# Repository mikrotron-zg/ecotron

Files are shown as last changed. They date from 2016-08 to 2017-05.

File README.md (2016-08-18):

# ecotron
IoT trashcan by http://www.DIYKits.eu/

For hardware and related instructions, see
https://hackaday.io/project/13111-internet-of-trash

Software is split in three parts:

1) arduino
Firmware that performs measurements, and sends the data to the sever.
Build and install with Arduino IDE.

2) server
Collection of Java servlets to receive the data from devices, and display the data to clients.
Build with 'ant war', then deploy ecotron-server.war to your app server.

3) webapp
A web application that reads the data from the server, and displays it on the map.
Build with 'mvn clean install', then deploy target/ecotronmap-demo.war to your app server.

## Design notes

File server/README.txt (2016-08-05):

Server that receives the data from device(s) and stores them to the database.

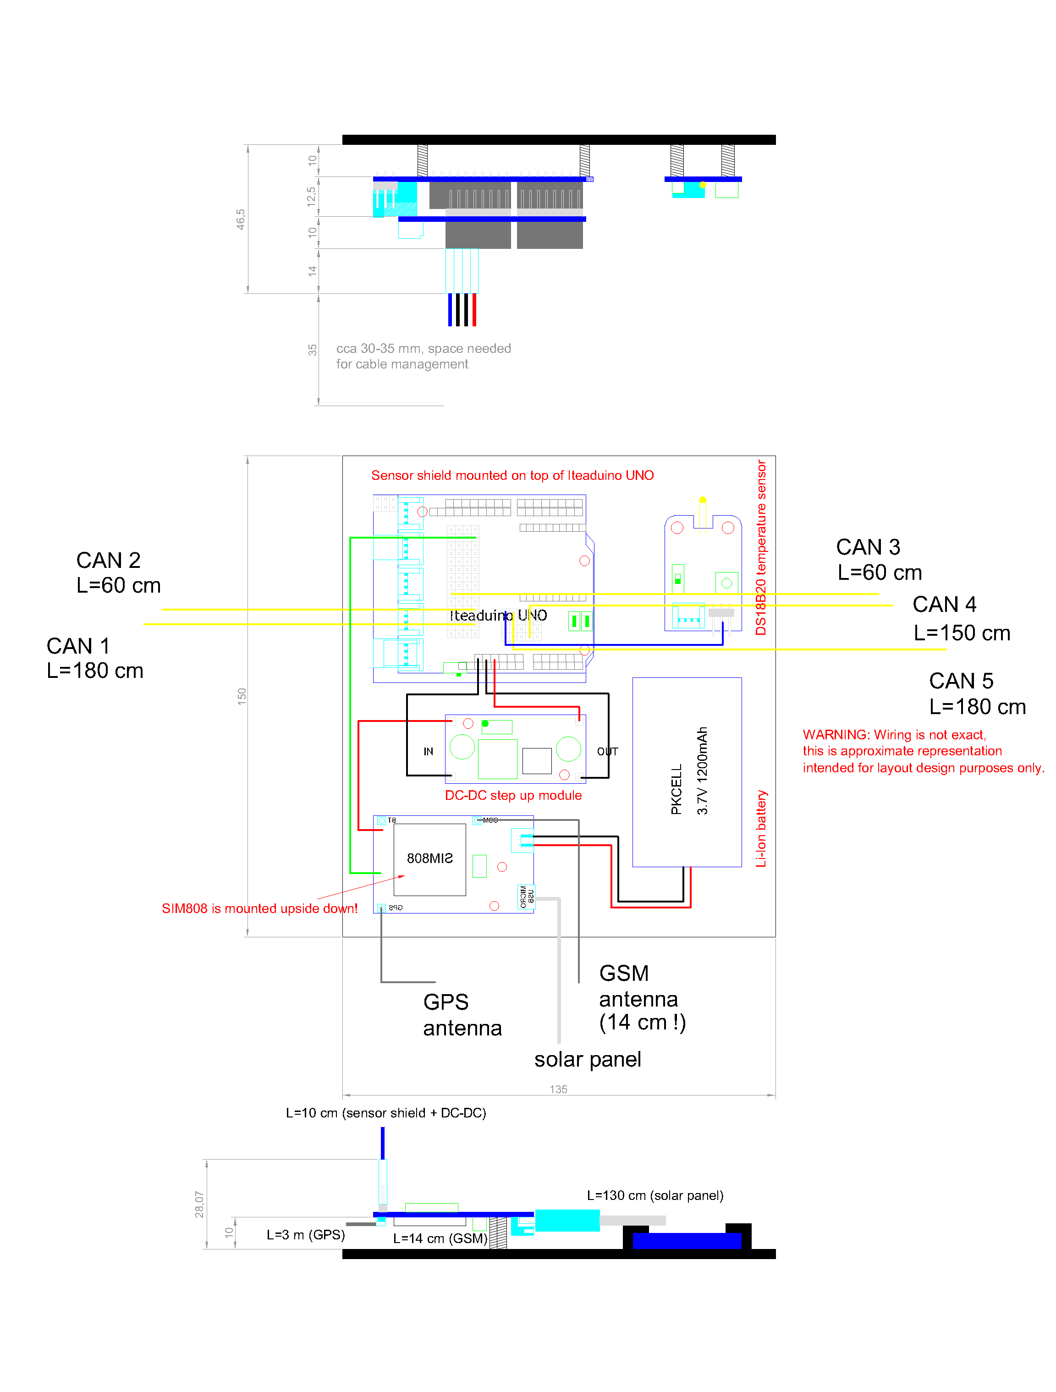
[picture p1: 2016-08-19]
hardware/EcotronControllerBox.png

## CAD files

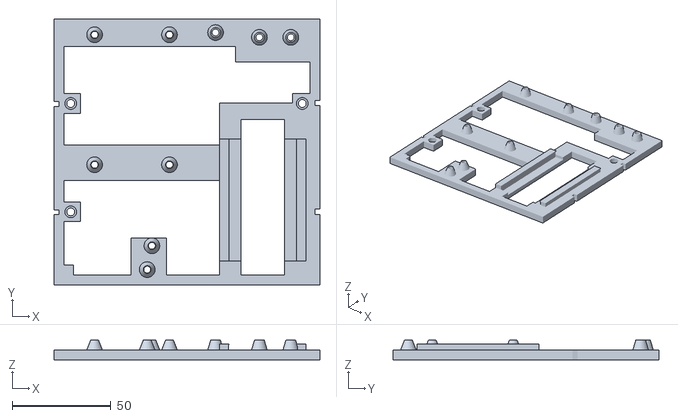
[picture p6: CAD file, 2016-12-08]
hardware/EcotronControllerBoxMount.stl
135.0 x 134.8 x 10.0

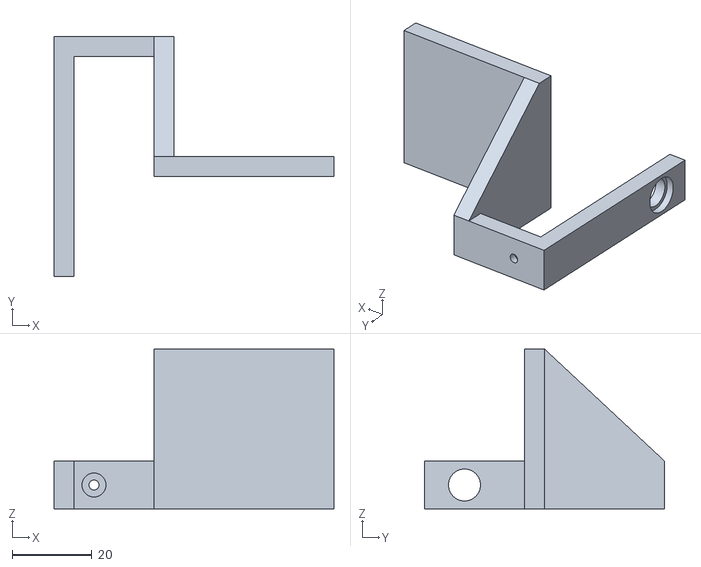
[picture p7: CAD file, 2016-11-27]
hardware/Antennas_mount.stl
70.0 x 60.0 x 40.0

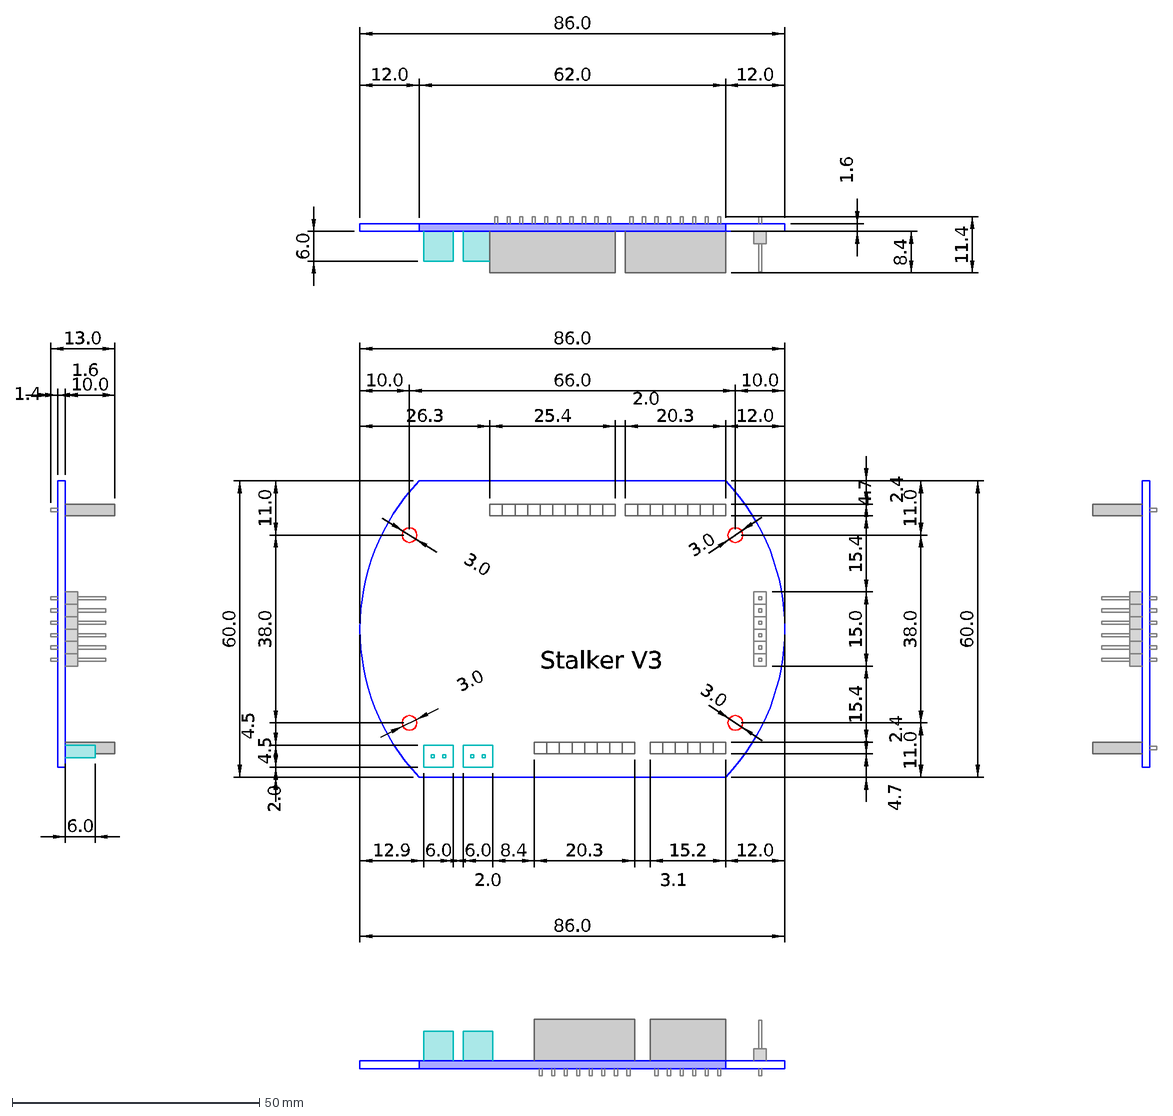
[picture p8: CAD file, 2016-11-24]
hardware/SeeeduinoStalkerV3.dxf
Stalker V3
86.0
12.0
62.0
10.0
66.0
26.3
25.4
2.0
20.3
60.0
11.0
38.0
4.7
2.4
15.4
15.0
3.0
11.4
8.4
1.6
6.0
12.9
3.1
15.2
4.5
13.0
1.4

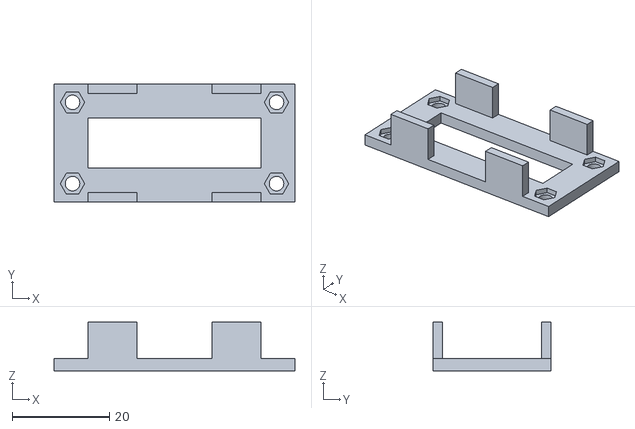
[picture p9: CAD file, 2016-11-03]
hardware/HC-SR04_mount.stl
49.5 x 24.3 x 10.0

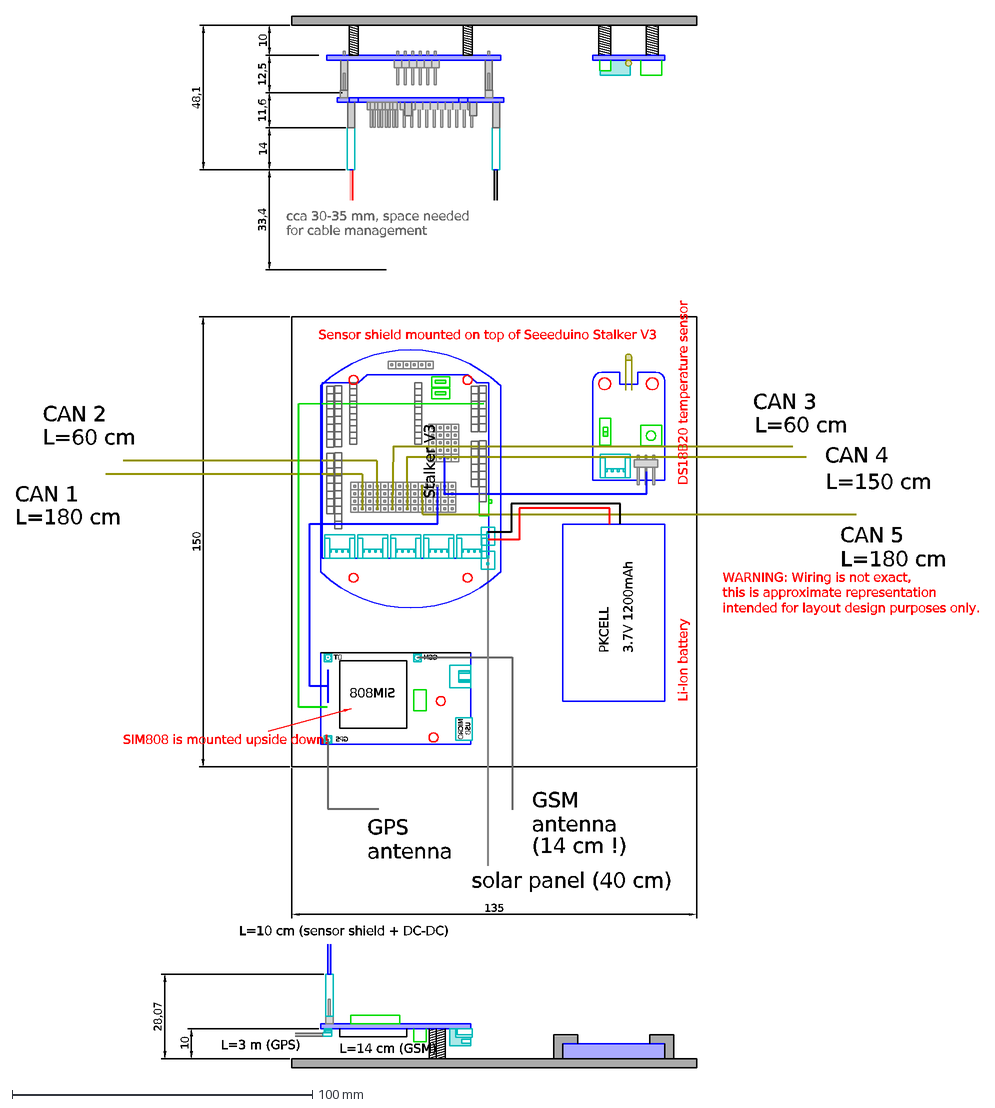
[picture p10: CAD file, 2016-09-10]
hardware/EcotronControllerBox.dxf
GSM
BT
GPS
SIM808
MICRO
USB
PKCELL
3.7V 1200mAh
135
150
10
28,07
48,1
12,5
11,6
14
33,4
cca 30-35 mm, space needed
for cable management
CAN 1
CAN 2
CAN 3
CAN 4
CAN 5
antenna
solar panel (40 cm)
WARNING: Wiring is not exact,
L=3 m (GPS)
L=10 cm (sensor shield + DC-DC)
L=14 cm (GSM)
(14 cm !)
this is approximate representation
L=180 cm
L=60 cm
L=150 cm
intended for layout design purposes only.
SIM808 is mounted upside down!
Sensor shield mounted on top of Seeeduino Stalker V3
DS18B20 temperature sensor
Li-Ion battery
Stalker V3

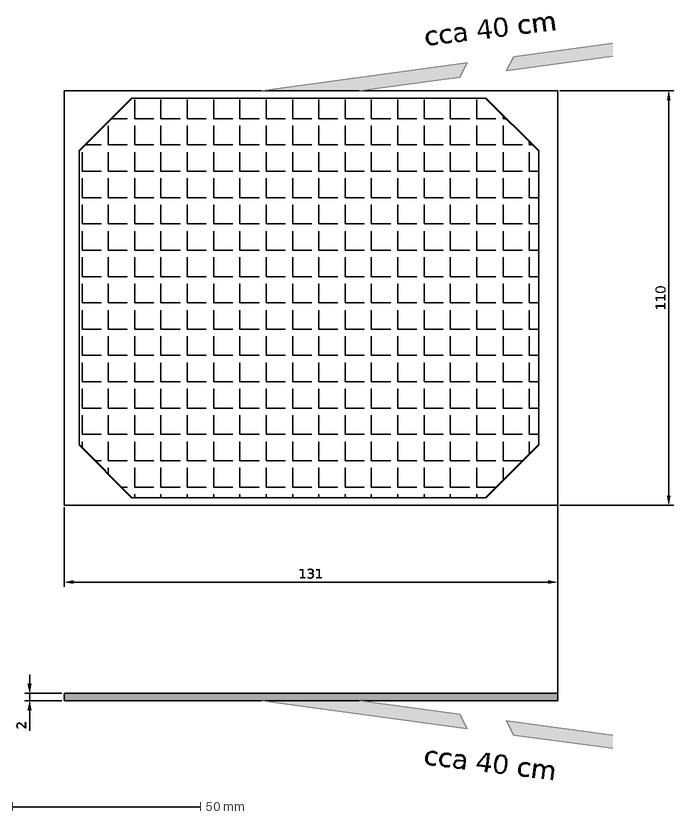
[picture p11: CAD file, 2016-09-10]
hardware/SolarPanel.dxf
cca 40 cm
131
110
2

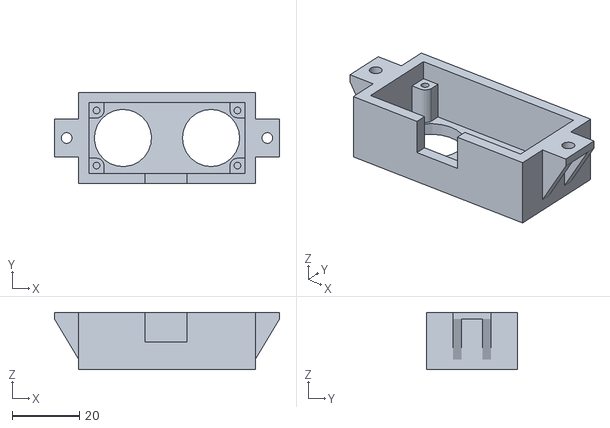
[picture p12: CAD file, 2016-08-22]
hardware/HC-SR04_housing.stl
66.9 x 27.0 x 17.0

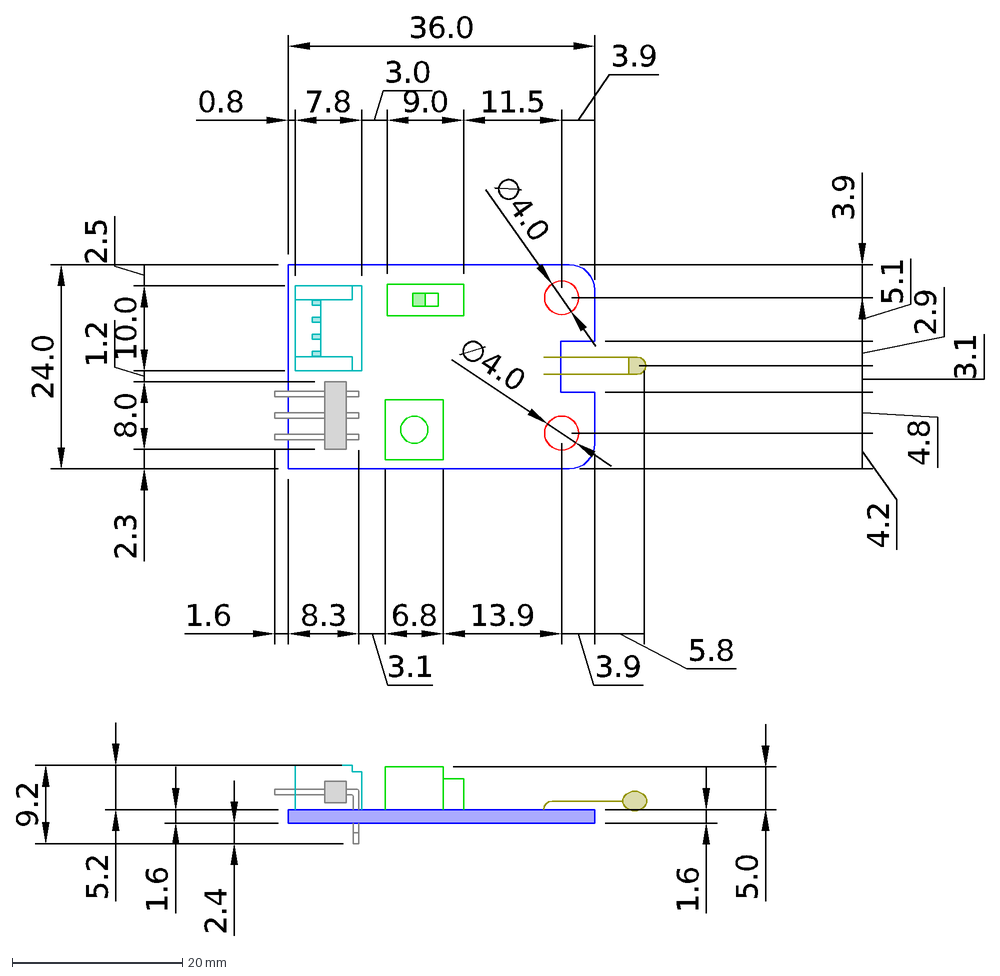
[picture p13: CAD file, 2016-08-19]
hardware/Temp_sensor_DS18B20.dxf
36.0
0.8
7.8
3.0
9.0
11.5
3.9
24.0
2.3
8.0
1.2
10.0
2.5
1.6
8.3
3.1
6.8
13.9
5.8
5.1
2.9
4.8
4.2
9.2
5.2
2.4
5.0
∅4.0

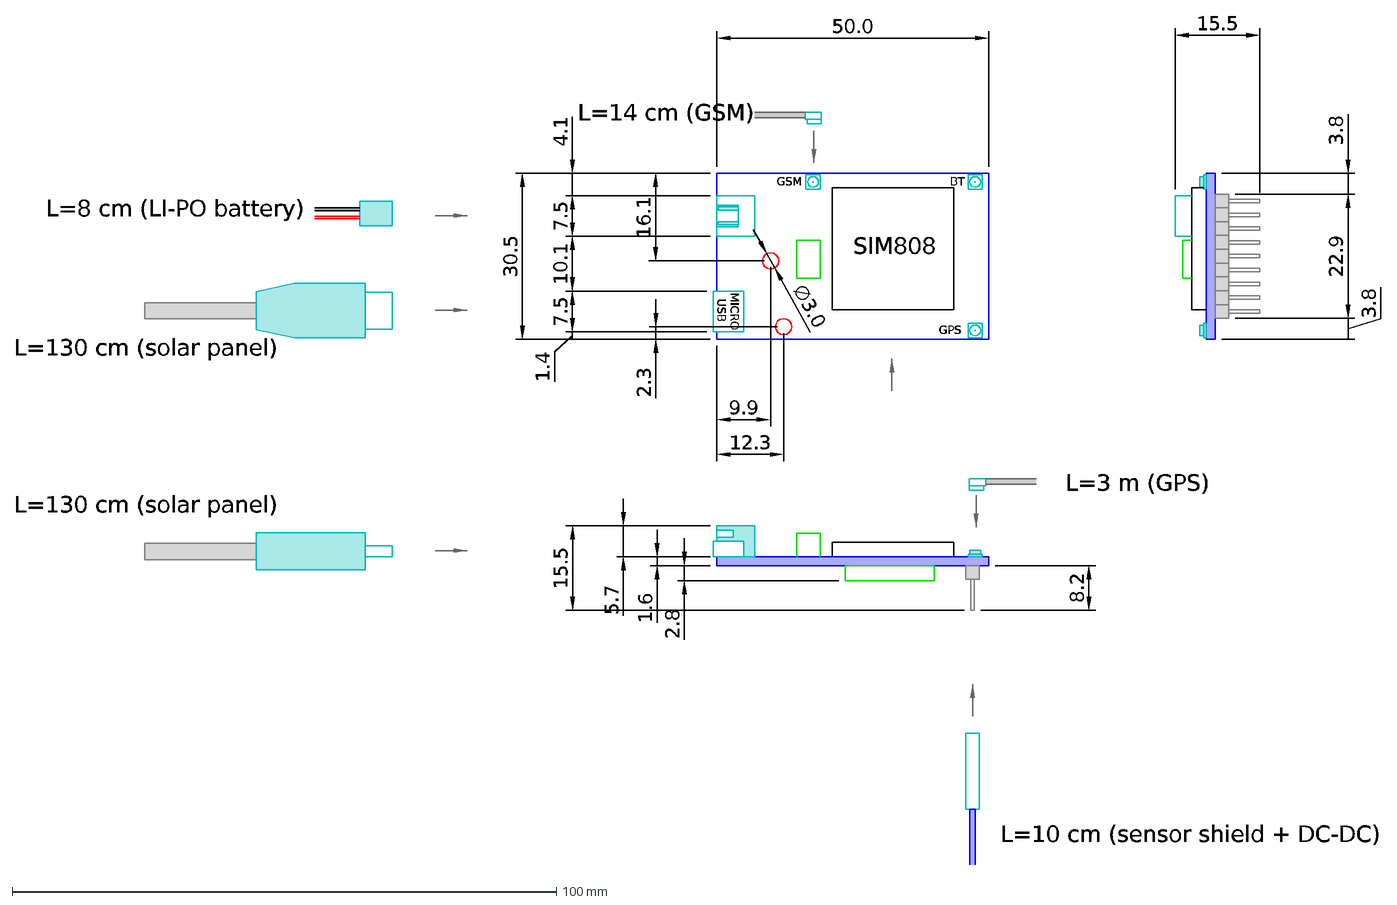
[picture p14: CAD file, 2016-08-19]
hardware/SIM808.dxf
GSM
BT
GPS
SIM808
MICRO
USB
L=3 m (GPS)
L=14 cm (GSM)
30.5
4.1
7.5
10.1
1.4
16.1
2.3
9.9
12.3
∅3.0
50.0
15.5
5.7
1.6
2.8
8.2
3.8
22.9
L=8 cm (LI-PO battery)
L=130 cm (solar panel)
L=10 cm (sensor shield + DC-DC)

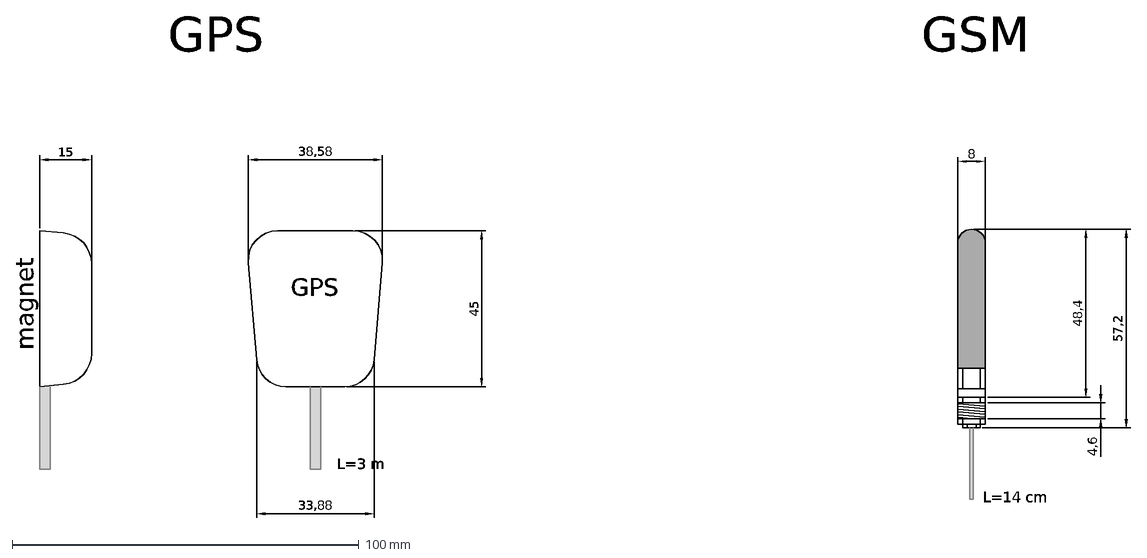
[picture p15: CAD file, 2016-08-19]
hardware/Antennas.dxf
GPS
38,58
33,88
45
15
GSM
magnet
8
57,2
48,4
4,6
L=14 cm
L=3 m

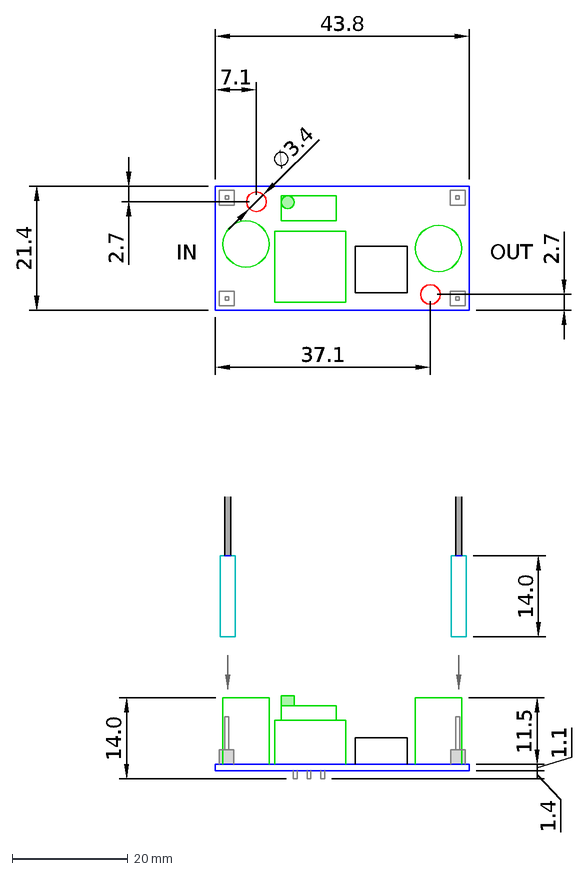
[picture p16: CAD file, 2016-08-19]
hardware/DC-DC_step-up.dxf
IN
OUT
43.8
7.1
21.4
2.7
37.1
∅3.4
14.0
11.5
1.1
1.4

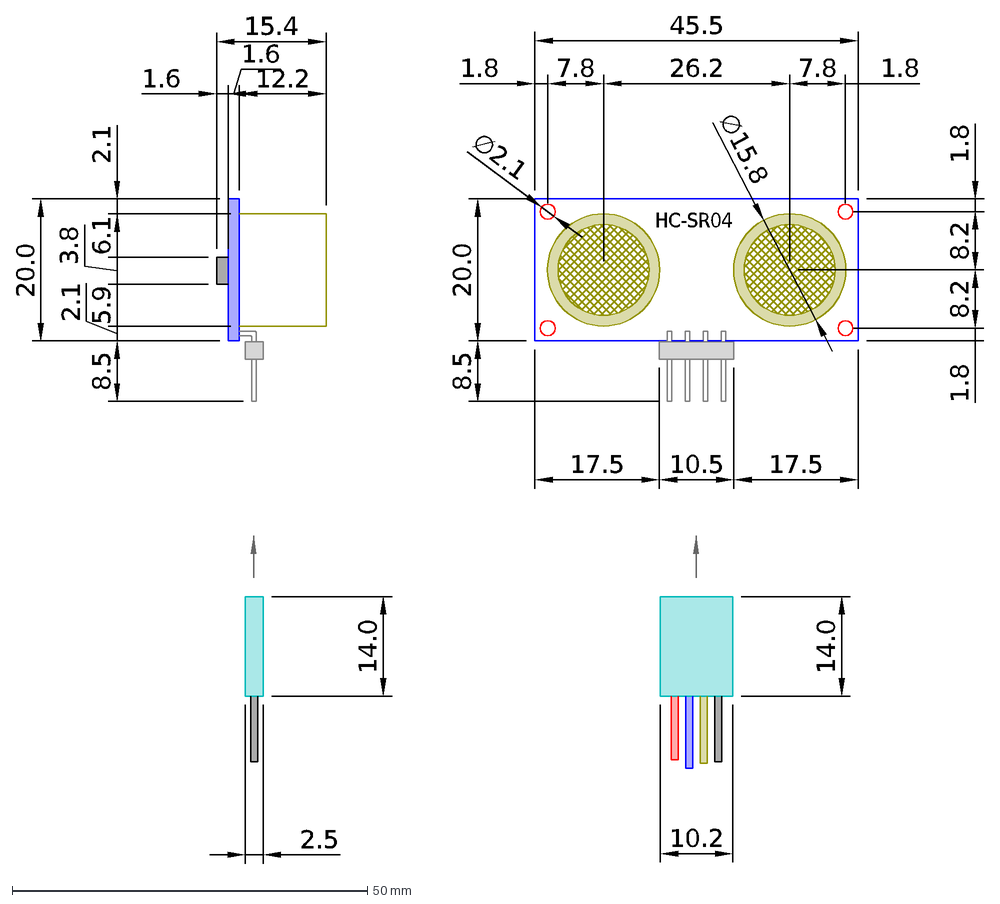
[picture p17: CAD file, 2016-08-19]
hardware/HC-SR04.dxf
HC-SR04
45.5
1.8
7.8
26.2
8.2
20.0
8.5
17.5
10.5
15.4
1.6
12.2
2.1
6.1
3.8
5.9
∅2.1
∅15.8
14.0
10.2
2.5

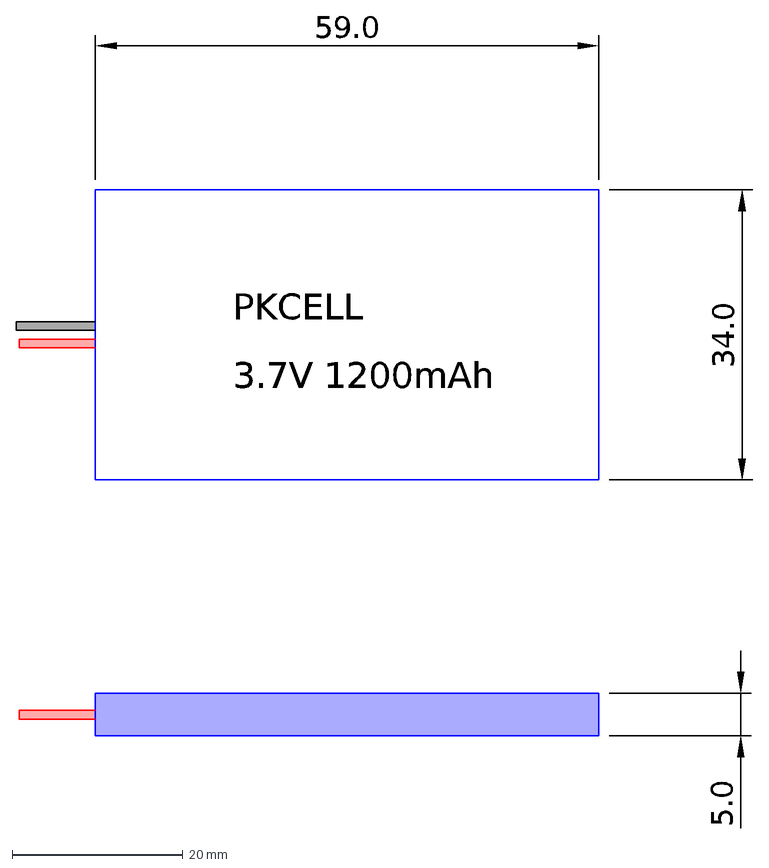
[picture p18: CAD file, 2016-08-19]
hardware/Li-Ion_1200.dxf
PKCELL
3.7V 1200mAh
59.0
34.0
5.0

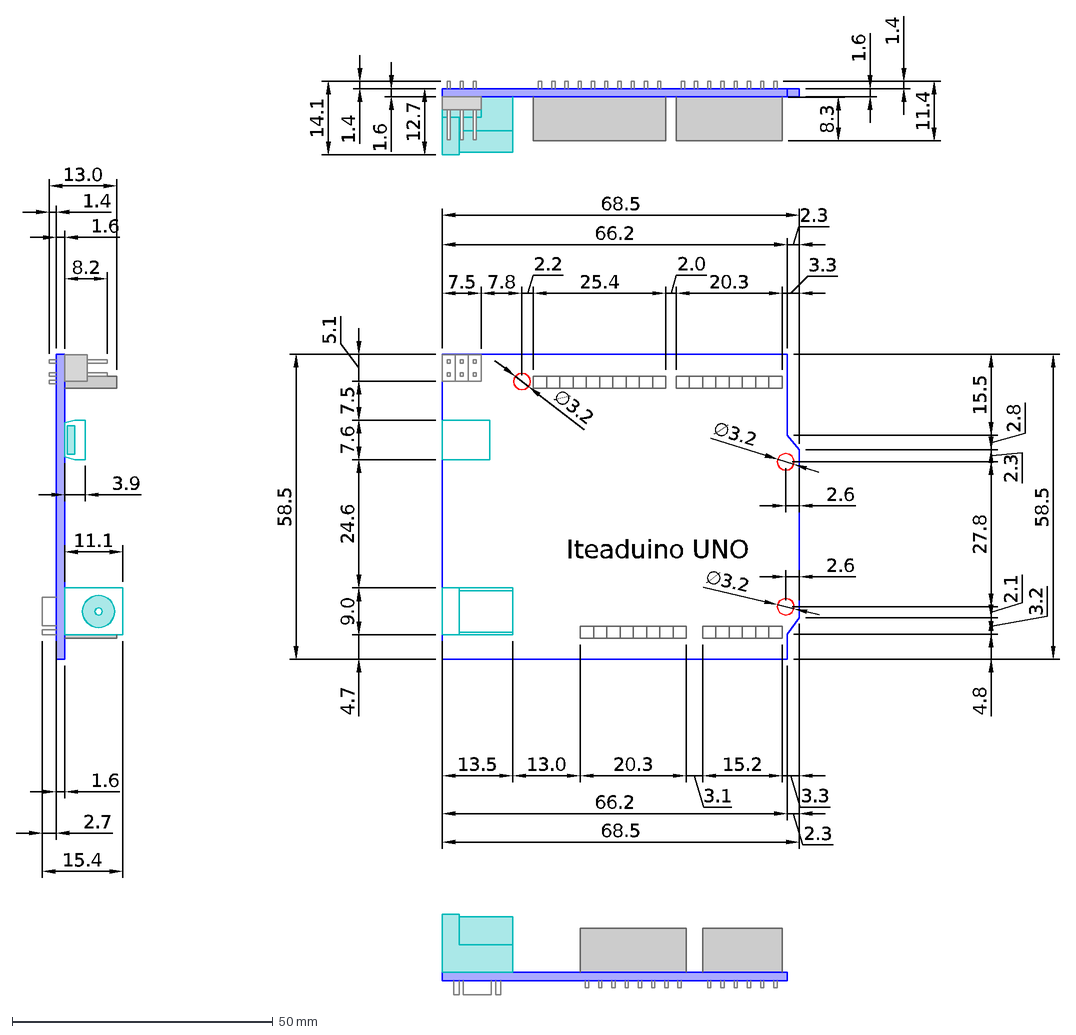
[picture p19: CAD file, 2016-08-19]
hardware/IteaduinoUno.dxf
68.5
66.2
2.3
13.5
13.0
20.3
3.1
15.2
3.3
2.6
58.5
4.8
3.2
2.1
27.8
2.8
15.5
∅3.2
7.5
7.8
2.2
25.4
2.0
1.4
1.6
8.2
15.4
2.7
11.1
3.9
4.7
9.0
24.6
7.6
5.1
14.1
11.4
8.3
12.7
Iteaduino UNO

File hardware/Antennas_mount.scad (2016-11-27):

//Antennas mount

ex=0.1;         //utility

mount_thickness=5;
mount_width=12;
mount_length=30;
mount_hole_x=10;
mount_hole_dia=2.5;
mount_hole_head_dia=6;
mount_hole_head_height=3;
GSM_mount_height=60;
GSM_mount_length=20;
GSM_mount_hole_dia=8;
GSM_mount_hole_height=50;
GPS_mount_height=35;
GPS_mount_width=40;
GPS_mount_length=45;
$fn=40;

//start
rotate([90, 0, 0]) antennas_mount();

module antennas_mount(){
    mount_base();
    GSM_mount();
    GPS_mount();
}

module mount_base(){
    difference(){
        cube([mount_length, mount_width, mount_thickness]);
        translate([mount_hole_x, mount_width/2, -ex]) 
            cylinder(h=mount_thickness-mount_hole_head_height+2*ex, d=mount_hole_dia);
        translate([mount_hole_x, mount_width/2, mount_thickness-mount_hole_head_height]) 
            cylinder(h=mount_hole_head_height+ex, d=mount_hole_head_dia);
    }
}

module GSM_mount(){
    difference(){
        cube([mount_thickness, mount_width, GSM_mount_height]);
        translate([-ex, mount_width/2, GSM_mount_hole_height]) 
            rotate([0, 90, 0]) union(){
                cylinder(h=mount_thickness+2*ex, d=GSM_mount_hole_dia);
                cylinder(h=mount_thickness-3+ex, d=GSM_mount_hole_dia+2);
            }
    }
}

module GPS_mount(){
    translate([mount_length-mount_thickness, 0, 0]) 
        cube([mount_thickness, mount_width, GPS_mount_height]);
    translate([mount_length-mount_thickness, 0, GPS_mount_height-mount_thickness]) 
        cube([GPS_mount_length, GPS_mount_width, mount_thickness]);
    translate([mount_length-mount_thickness,GPS_mount_width, GPS_mount_height-mount_thickness])     rotate([180, 0, 0]) 
            prism(mount_thickness, GPS_mount_width-mount_width, GPS_mount_height-mount_thickness);
}

 module prism(l, w, h){
       polyhedron(
               points=[[0,0,0], [l,0,0], [l,w,0], [0,w,0], [0,w,h], [l,w,h]],
               faces=[[0,1,2,3],[5,4,3,2],[0,4,5,1],[0,3,4],[5,2,1]]
               );
 }

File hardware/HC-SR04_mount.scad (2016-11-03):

//HC-SR04 mount

ex=0.1;         //utility
hole_dia=3;   //hole diameter
hole_offset=1.8;  //hole center offset from the board edge
base_height=2.5;  //mount base height
base_length=45.5;
base_width=20.3;
holder_width=2;
holder_length=10;
holder_height=10;
holder_offset=5;
inner_offset=5;

main();

module main(){
    difference(){
        translate([-holder_width, -holder_width, 0]) 
            cube([base_length+2*holder_width, base_width+2*holder_width, base_height]);
        holes();
        translate([inner_offset, inner_offset, -ex]) cube([base_length-2*inner_offset, base_width-2*inner_offset, base_height+2*ex]);
    }
    holders();
}

module holes(){
    translate([hole_offset, hole_offset, -ex]) hole();
    translate([base_length-hole_offset, hole_offset, -ex]) hole();
    translate([base_length-hole_offset, base_width-hole_offset, -ex]) hole();
    translate([hole_offset, base_width-hole_offset, -ex]) hole();
}

module hole(){
    union(){
        cylinder(d=hole_dia, h=base_height+2*ex, $fn=25);
        M2nut();
    }
}

module M2nut(nutHeight=1){
    translate([0,0, base_height-nutHeight]) 
        cylinder(r = 4 / 2 / cos(180 / 6) + 2*ex, h=nutHeight+2*ex, $fn=6);
}

module holders(){
    translate([holder_offset, -holder_width, 0]) holder();
    translate([base_length-holder_length-holder_offset, -holder_width, 0]) holder();
    translate([base_length-holder_length-holder_offset, base_width, 0]) holder();
    translate([holder_offset, base_width, 0]) holder();
}

module holder(){
    cube([holder_length, holder_width, holder_height]);
}

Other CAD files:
hardware/IteaduinoSensorShield.dxf
hardware/EcotronControllerBoxMount.skp
hardware/HC-SR04_housing.skp

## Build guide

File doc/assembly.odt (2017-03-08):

Ecotron

Assembly Manual

# Pin mapping

## SIM808 Module

SIM808 | Arduino
RX | 10
TX | 8
DTR | 11
RI | 12
PWR | 13
RST | Not used
VIO | Vcc
GND | Any GND
VBAT | Battery

Notes:

- RX/TX use SoftwareSerial library

- avoid using pin 13 as input

- SIM808 should not be powered via Seeeduino Stalker Vcc, which is regulated, for it may not be able to give enough power. Direct power supply from battery give better overall results.

## Temperature Sensor

Temperature sensor | Arduino
Vcc | Any Vcc
GND | Any GND
Signal | A0

## Ultrasonic Rangefinder Sensors

Can number | HC-SR04 module | Arduino
Far right (can 1) | Trigger | 0
| Echo | 1
Far left (can 5) | Trigger | 4
| Echo | 5
Middle left (can 4) | Trigger | 6
| Echo | 7
Close right (can 2) | Trigger | A1
| Echo | A2
Close left (can 3) | Trigger | 3 (digital!)
| Echo | A3

Notes:

- Vcc and GND required for each sensor can be connected to any Vcc and GND

- positions refer to the actual container with 5 separate bins left and right as seen by device from within the container (not outside viewer!)

- from the outside, cans are conveniently ordered 1-5 from left to right

## Built-in connections

Sensor power switch – high on | 9
RTC Hardware interrupt | 2
RTC I2C SDA | A5
RTC I2C SCL | A4

Notes:

- Seeeduino Stalker 3.1 has a built-in FET that powers Vcc, controlled by pin 9 – use it to supply power to sensors

- RTC interrupt pin can be changed – don't

# Assembly

## Seeeduino Stalker

SD Card socket does not fit tight, fix it using some duct tape.

TODO: pic

## SIM808

All pins of SIM808 except RST are used, antennae are connected via uFL sockets.

TODO: pic

SIM card socket does not fit tight. To keep SIM in place, use a bit of duct tape.

TODO: pic

## HC-SR04 sensors

Note that wires are crossed. Labelling is handy.

TODO: pics

Sensor 3 is connected to one digital and one analog pin!

TODO: pic

## Sensor Shield

Note that battery and solar panel cannot be plugged in while sensor shield is in place – this is design flaw of Seeeduino Stalker.

However, plugging sensor cables is easier when shield is in place.

TODO: pic

## Power supply

Prepare the cable first: JST-PH goes to battery slot of Stalker, and another wire to VBAT of SIM808 module.

TODO: pic

Guess what, solar panel cables need to be soldered.

TODO: pic

And, plug them into Stalker, add sensor shield on top of it.

TODO: pic

# Programming

## Connecting programmer

Connect the thing to programmer – we use Foca by Itead.

TODO: pic

Plug USB cable into PC.

## Firmware changes

Each SIM cart has it's own PIN. In addition, depending on mobile operator, APN may need to be changed.

Look up PIN and APN in SIM808.ino, and set to your values, i.e.

// carrier data for GSM network

String PIN="8215";

String APN="mobileinternet.tele2.hr";

Server URL also needs to be changed, at least Station ID:

// server data

String SERVER="http://www.mikrotron.hr/ecotronserver/upload?stationId=gama";

## Testing

TODO

at+cmee=2

// runtime options

#define DEBUG true // run in debug mode

#define MANUAL true // manual control mode

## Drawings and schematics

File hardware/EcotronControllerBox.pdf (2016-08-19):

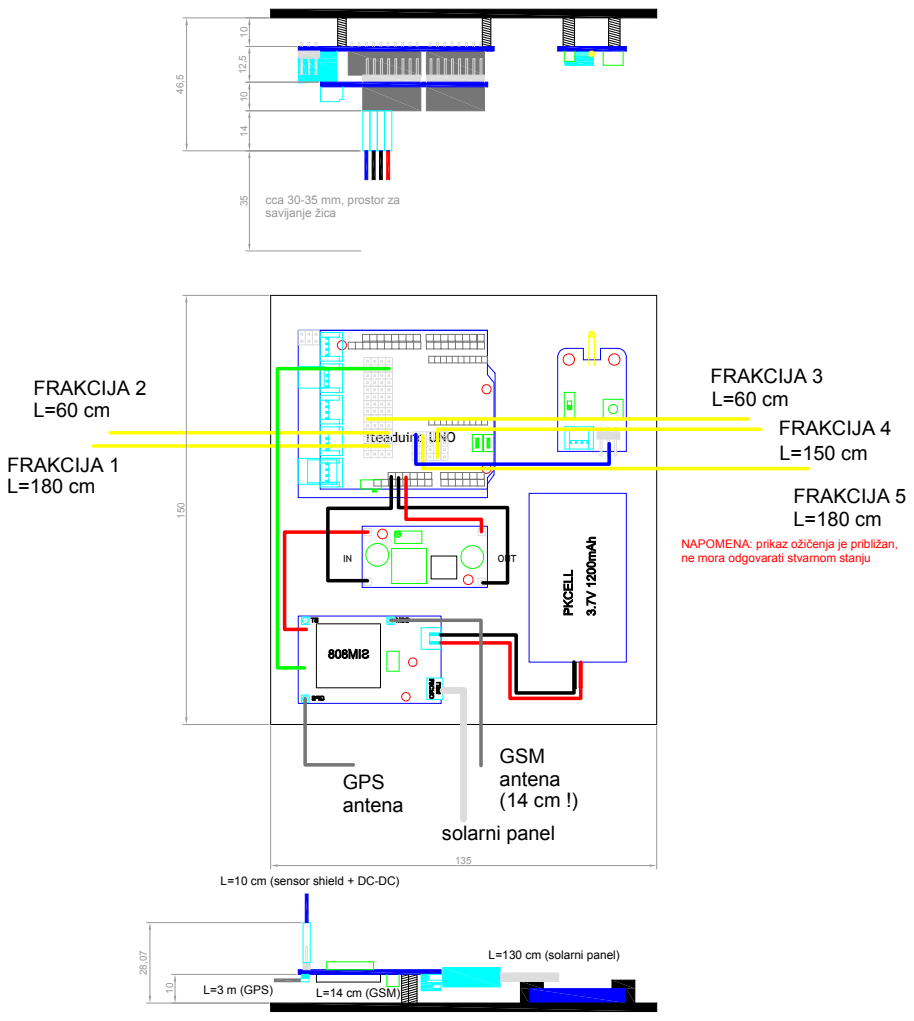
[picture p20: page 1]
Iteaduino; UNO; OUT; FRAKCIJA 1; FRAKCIJA 2; FRAKCIJA 3; FRAKCIJA 4; FRAKCIJA 5; GPS antena; GSM antena; solarni panel; L=3 m (GPS); L=14 cm (GSM)

cca 30-35 mm, prostor za
savijanje žica

NAPOMENA: prikaz ožičenja je približan,
ne mora odgovarati stvarnom stanju

L=10 cm (sensor shield + DC-DC)

L=130 cm (solarni panel)

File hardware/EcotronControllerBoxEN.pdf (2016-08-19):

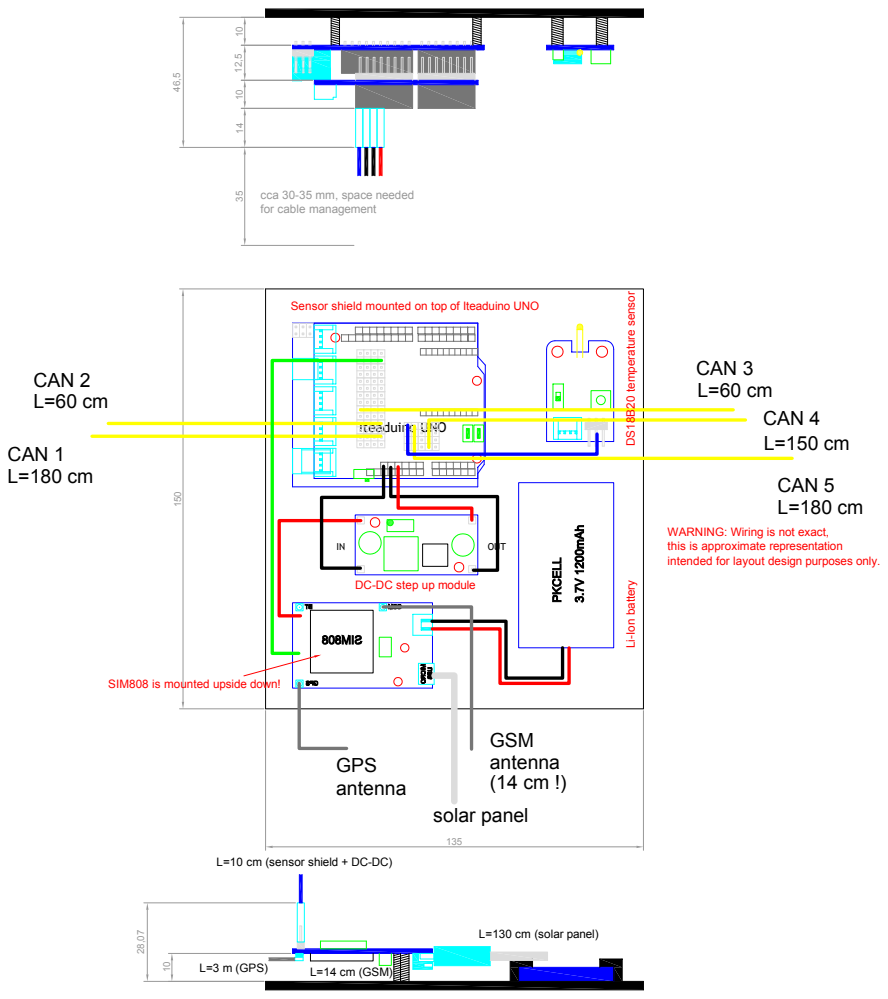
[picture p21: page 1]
Iteaduino; UNO; OUT; CAN 1; CAN 2; CAN 3; CAN 4; CAN 5; GPS antenna; GSM antenna; solar panel; L=3 m (GPS); L=14 cm (GSM)

cca 30-35 mm, space needed
for cable management

DS18B20 temperature sensor Li-Ion battery

Sensor shield mounted on top of Iteaduino UNO

WARNING: Wiring is not exact,
this is approximate representation
intended for layout design purposes only.

DC-DC step up module

SIM808 is mounted upside down!

L=10 cm (sensor shield + DC-DC)

L=130 cm (solar panel)

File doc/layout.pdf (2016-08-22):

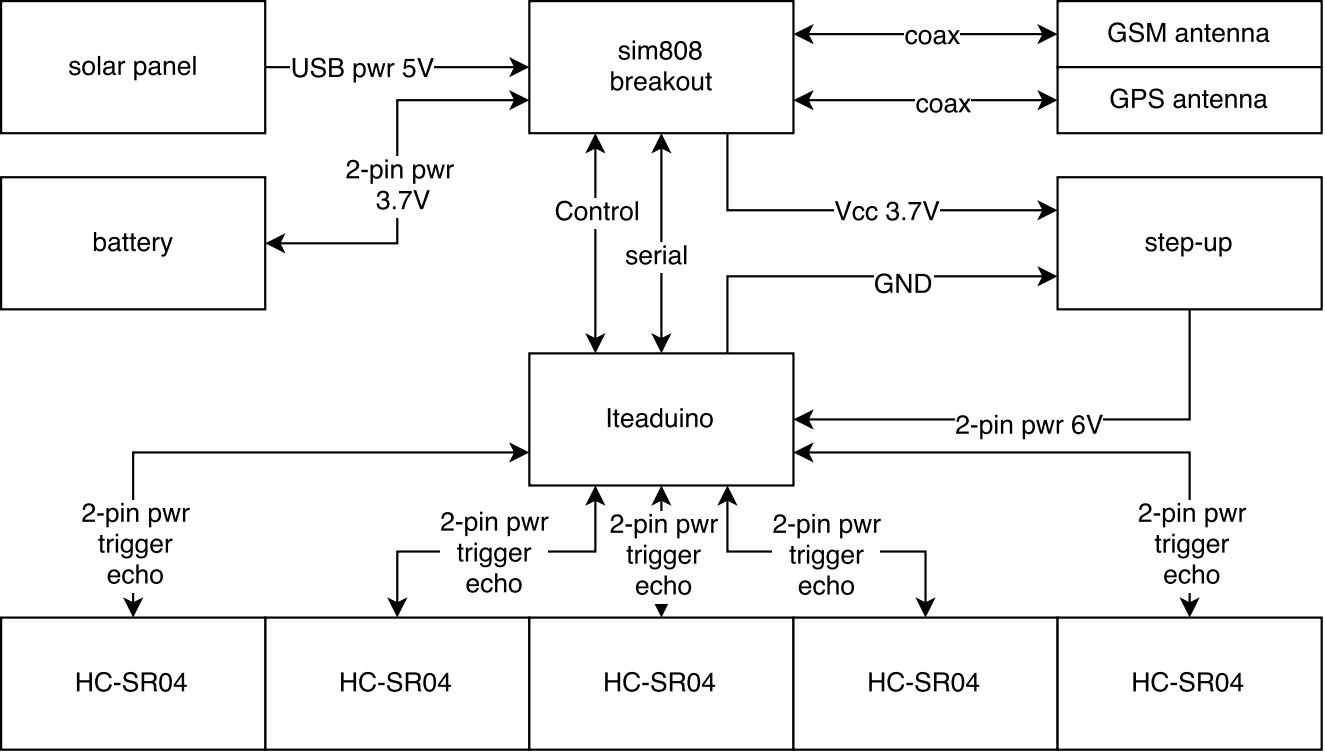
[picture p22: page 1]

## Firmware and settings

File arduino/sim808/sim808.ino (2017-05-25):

// Ecotron node firmware
// Tomislav Mamić for Mikrotron d.o.o 2016.

// --- pin map ---

// - sim808
// 8  - TX
// 10 - RX
// 11 - DTR
// 12 - RI
// 13 - PWR

// - HC-SR04
// 0  - P1 - far right 180 ---! overlaps with hardware serial - disconnect can0 sensor before debugging !---
// 1  - M1
// 4  - P5 - far left 180
// 5  - M5
// 6  - P4 - middle left 150
// 7  - M4
// A1 - P2 - close right 60
// A2 - M2
// A3 - P3 - close left 60
// 3  - M3

// - Assorted
// A0 - temp. sensor
// A5 - I2C SDA
// A4 - I2C SCL
//  9 - sensor power control

#include <avr/sleep.h>
#include <avr/power.h>
#include <SoftwareSerial.h>
#include <Wire.h>
#include "DS1337.h"
#include "SeeeduinoStalker.h"

// runtime options
#define DEBUG false     // run in debug mode
#define MANUAL false    // manual control mode
#define CHECKHC false   // sensor checking loop
#define CHECKRTC false  // rtc checking loop
#define HCTO 15000      // HC-SR40 distance sensor timeout
#define SIMTO 60000     // sim808 general timeout
#define MAXERRS 5       // consecutive error tolerance

// software serial to sim808
SoftwareSerial sim808(10,8);
//SoftwareSerial sim808(8,10);

// sim808 controls
#define RI 12    // status
#define PWR 13   // soft power switch
#define DTR 11   // sleep

// stalker & RTC control
// brown out detection disabling function - copy pasta
#define sleep_bod_disable() \
{ \
  uint8_t tempreg; \
  __asm__ __volatile__("in %[tempreg], %[mcucr]" "\n\t" \
                       "ori %[tempreg], %[bods_bodse]" "\n\t" \
                       "out %[mcucr], %[tempreg]" "\n\t" \
                       "andi %[tempreg], %[not_bodse]" "\n\t" \
                       "out %[mcucr], %[tempreg]" \
                       : [tempreg] "=&d" (tempreg) \
                       : [mcucr] "I" _SFR_IO_ADDR(MCUCR), \
                         [bods_bodse] "i" (_BV(BODS) | _BV(BODSE)), \
                         [not_bodse] "i" (~_BV(BODSE))); \
}
DS1337 rtc;
DateTime dtbuff;
Stalker stalker;
boolean hflag=false;
// wakeup timing [when to wake up, interval, interval on/off flag*] *flag = 0 --> does not add to the interval
int wu_hr[3];
int wu_min[3];

// temperature sensor
#define TMP A0   // signal pin
#define RESISTOR 10000  // sensor internal resistor value
double Rval[]={5.301,4.48,3.62};
double Tval[]={-40,0,50};

// carrier data for GSM network
//String PIN="8215";
String PIN="7312";
//String PIN="2147";
//String PIN="1024";
//String APN="internet.ht.hr";
//String APN="mobileinternet.tele2.hr";
String APN="web.htgprs";

// server data
String SERVER="http://www.mikrotron.hr/ecotronserver/upload?stationId=beta";
String gpsdata="";
String gpsp="&gpsInfo=";
String batp="&batInfo=";

// generic strings for memory saving
String ok="OK";

// HC-SR40 trigger/echo pins and states
//int marcos[]={1,A2,3,7,5};
//int polos[]={0,A1,A3,6,4};
int triggerPins[]={0,A1,3,6,4};
int echoPins[]={1,A2,A3,7,5};
int states[]={-1,-1,-1,-1,-1};

void setup(){
  // configure atmega pins
  pinsetup();
  // set initial send flag (so that device sends when first turned on, for debug purposes)
  hflag=true;
  // shut down sensor shield
  ssOff();
  // start serial in debug mode
  if(DEBUG)Serial.begin(9600);
  delay(500);
  // loop sensor check on demand
  if(CHECKHC){while(1)debugHCSR04();}
  // make sure RTC works if device isn't started in manual mode
  if(!checkRTC()&&!MANUAL){debugPrintln(F("RTC DOWN"));while(1);}else{standardRTCSetup();}
  // loop RTC check on demand
  //if(CHECKRTC){while(1)debugRTC();}
  // open serial to sim808
  sim808.begin(9600);
  // power sensor shield up
  ssOn();
  // start up sim808
  sim808su();
  sim808wu();
  //if (MANUAL) verboseErrors();
}

void loop(){
  // handle interrupt
  debugPrintln("hflag = "+String(hflag));
  dtbuff=rtc.now();
  debugPrintln("Woke up on " + String(dtbuff.hour())+":"+String(dtbuff.minute()));
  //if(hflag&&!MANUAL){ //hflag=0 prevents everything from working - disabled for the time being
  if(!MANUAL){
    // turn stuff on
    ssOn();
    sim808su();
    sim808wu();
    // check if sim808 works
    checkModule();
    // ping trash cans
    updateStates();
    // ignore SIM connection error and go back to sleep
    if(!connectSIM())return;
    // report state if connection is successful
    report();
  }
  if(!MANUAL)hibernate();else debugStream();
  //ToDo: various recovery methods from unexpected events
  // -- uncalled for restarts
  // -- network issues
  // -- dead sensors
}

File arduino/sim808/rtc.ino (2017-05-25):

boolean checkRTC(){
  // check if RTC responds via I2C
  if(!rtc.begin())return false;
  return true;
}

void setAlarmClock(){
  // calculate desired wakeup time to write to the RTC at bed time
  // read now
  dtbuff=rtc.now();
  wu_min[0]=dtbuff.minute();
  wu_hr[0]=dtbuff.hour();
  // wrap over 24h and 60min
  if(wu_min[2]){
    wu_min[0]+=wu_min[1];
    wu_hr[0]+=(wu_min[0])>59;
  }
  if(wu_hr[2])wu_hr[0]+=wu_hr[1];
  wu_min[0]%=60;
  wu_hr[0]%=24;
  debugPrintln("Current time "+String(dtbuff.hour())+":"+String(dtbuff.minute()));
  debugPrintln("Offset " + String(wu_hr[1])+":"+String(wu_min[1]));
  debugPrintln("Wake up time "+String(wu_hr[0])+":"+String(wu_min[0]));
}

//void debugRTC(){
//  // to be called during sleep cycle debugging - set custom wakeup interval here
//  dumpNow();
//  wu_hr[1]=0;
//  wu_min[1]=2;
//  wu_hr[2]=0;
//  wu_min[2]=1;
//  hibernate();
//}

void standardRTCSetup(){
  // to be called as sleep interval configuration during normal device operation
  wu_hr[1]=3;
  wu_hr[2]=1;
  wu_min[1]=58;
  wu_min[2]=1;
}

void hibernate(){
  // set the clock, shut stuff down
  setAlarmClock();
  sim808off();
  sim808sleep();
  ssOff();
  hcshut();
  dtbuff=rtc.now();
  // drop the interrupt flag
  hflag=false;
  // make sure RTC understands that we've dealt with its alert
  while(!digitalRead(2)){rtc.clearINTStatus();delay(100);}
  debugPrintln(F("INIT SLEEP"));
  // set RTC interrupt time
  rtc.enableInterrupts(wu_hr[0],wu_min[0],0);
  delay(100);
  // unlock sleep functionality
  sleep_enable();
  // make sure interrupt can happen
  attachInterrupt(0, wuCall, LOW);
  // prepare the MCU for sleep
  set_sleep_mode(SLEEP_MODE_PWR_DOWN);
  cli();
  sleep_bod_disable();
  sei();
  power_all_disable();
  // stop MCU
  sleep_cpu();
  // !--code pauses here until interrupt occurs--!
  
  // lock MCU sleep functionality
  sleep_disable();
  // get all the MCU parts powered again
  power_all_enable();
  delay(100);
  // restore pin configuration
  hcopen();
  debugPrint(F("EXIT SLEEP"));
}

void wuCall(){
  // ISR
  sleep_disable();
  detachInterrupt(0);
  hflag=true;
}

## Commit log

2016-08-18 System now monitors battery status too
2016-08-19 Added hardware directory to the project
    [Antennas.dxf, DC-DC_step-up.dxf, EcotronControllerBox.dxf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]
2016-08-20 Small adjustments to controller box mount 3D model
    [EcotronControllerBoxMount.skp]
2016-08-22 Added HC-SR04 housnig model and stl
    [HC-SR04_housing.skp, HC-SR04_housing.stl]
2016-08-22 Addded battery info to webapp dialog box
2016-09-03 Changed hardware layout from UNO to Stalker
    [EcotronControllerBox.dxf, SeeeduinoStalkerV3.dxf]
2016-09-10 Changed solar panel and controller box internal wiring
    [EcotronControllerBox.dxf, SolarPanel.dxf]
2016-11-03 Added HC-SR04 mount model
    [HC-SR04_mount.scad, HC-SR04_mount.stl]
2016-11-24 Changed controller mount for new box and added antennas mount
    [Antennas_mount.scad, Antennas_mount.stl, EcotronControllerBoxMount.skp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]
2016-11-27 Corrections after testing controller and antennas mounts
    [Antennas_mount.scad, Antennas_mount.stl, EcotronControllerBoxMount.skp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]
2016-11-30 Power management improvements
2016-12-08 Final controller box mount design
    [EcotronControllerBoxMount.skp, EcotronControllerBoxMount.stl]
2017-02-24 improved code readability and debugging switched trigger and echo pins
2017-03-08 delta: 4th prototype on its way! And a bit of assembly manual.
2017-03-09 5th station assembled and tested, manual updated.
